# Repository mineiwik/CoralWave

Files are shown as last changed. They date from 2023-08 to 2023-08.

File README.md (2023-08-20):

# CoralWave

This repository contains the hardware design files for an RF transceiver system built using an ESP32-C3 module and a CC1101 RF chip. The communication between the ESP32-C3 and CC1101 is established through the Serial Peripheral Interface (SPI) protocol. The design is created using KiCad 7.

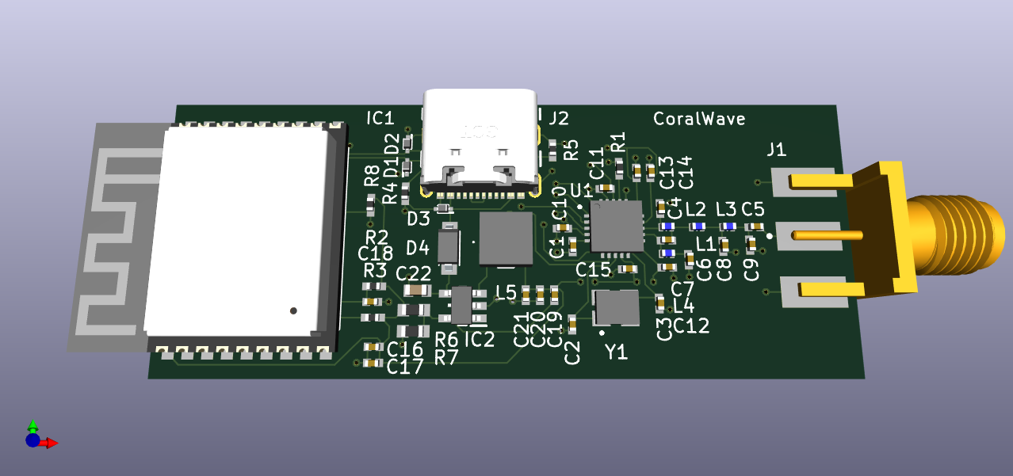
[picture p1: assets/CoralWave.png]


## Abstract

The project aims to create a versatile RF communication system by integrating the ESP32-C3 module and the CC1101 RF chip. The ESP32-C3 serves as the main controller, handling data processing and interfacing with external devices, while the CC1101 handles the RF communication with other compatible devices. This design allows for bi-directional communication over a designated RF frequency band, making it suitable for various applications such as replacing remote controls.

**Note:** The design around the CC1101 chip is tuned for the 315/433 MHz ISM/SRD frequency bands. (See the documentation of the [CC1101](https://www.ti.com/lit/ds/symlink/cc1101.pdf) chip for more information.)

## Opening the Design

Follow these steps to open the hardware design using KiCad 7:

1. Clone this repository to your local machine using the following command:

   ```
   git clone https://github.com/mineiwik/CoralWave.git
   ```

2. Launch KiCad 7.

3. Open the KiCad project by navigating to the project directory and locating the `.kicad_pro` file. This file stores the project information.

4. Once the project is open, you can access the schematic and PCB layout files by clicking on the respective buttons in the KiCad project manager.

5. Adjust the design and/or export the gerbel files for PCB production

## Design Files

The repository contains the following design files:

- Schematic files (`.kicad_sch`) - These files define the circuit connections and component values.
- PCB layout files (`.kicad_pcb`) - These files represent the physical arrangement of components on the PCB.
- Component libraries (see the `PCBLib` submodule) - Custom libraries that include footprints and symbols for the ESP32-C3, CC1101, and other components used in the design.

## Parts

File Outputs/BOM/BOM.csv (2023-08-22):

Id | Designator | Footprint | Quantity | Designation | Manufacturer Nr. | Mouser Nr.
1 | Y1 | NX3225GA16000MSTDCRG1 | 1 | NX3225GA-26MHZ | NX3225GA-26.000MHZ-EXS00A-CG01972 | 344-NX3225GA26MHZEXS
2 | C16,C1,C10 | Cap_Murata_GRM_0402 | 3 | 100nF | GRM155C71H104JE19J | 81-GRM155C71H104JE9J
3 | C2,C3 | Cap_Murata_GRM_0402 | 2 | 27pF | GRM1555C1H270JA01D | 81-GRM1555C1H270JA1D
4 | C5,C6,C13,C11,C12 | Cap_Murata_GRM_0402 | 5 | 220pF | GRM1555C1H221JA01J | 81-GRM1555C1H221JA1J
5 | U1 | CC1101RGP | 1 | CC1101RGP | CC1101RGPR | 595-CC1101RGPR
6 | R6 | R_Bourns_CR_0603 | 1 | 442k | CR0603-FX-4423ELF | 652-CR0603FX4423ELF
7 | C19 | Cap_Murata_GRM_0402 | 1 | 6.8pF | GRM1555C1E6R8BA01D | 81-GRM1555C1E6R8BA1D
8 | R8,R2,R3 | R_Vishay_CRCW_0402 | 3 | 10k | CRCW040210K0FKEDC | 71-CRCW040210K0FKEDC
9 | C22 | Cap_Murata_GRM_0603 | 1 | 4.7uF | GRM188R61C475KE11D | 81-GRM188R61C475KE1D
10 | R7 | R_Bourns_CR_0603 | 1 | 97.6k | CR0603-FX-9762ELF | 652-CR0603FX-9762ELF
11 | L3,L4,L1 | L_Murata_LQG_0402 | 3 | 27nH | LQG15HS27NJ02D | 81-LQG15HS27NJ02D
12 | C20,C17,C21 | Cap_Murata_GRM_0402 | 3 | 10uF | GRM155R61A106ME11D | 81-GRM155R61A106ME1D
13 | D4 | SOD3716X135N | 1 | B5819W-TP | B5819W-TP | 833-B5819W-TP
14 | D3,D2,D1 | SODFL1006X40N | 3 | CPDQ5V0-HF | CPDQ5V0-HF | 750-CPDQ5V0-HF
15 | R1 | R_KOA_RK_0402 | 1 | 56k | RK73H1ETTP5602F | 660-RK73H1ETTP5602F
16 | J1 | Molex-SD-73251-129 | 1 | 73251-1290 | 73251-1290 | 538-73251-1290
17 | R4,R5 | R_Vishay_CRCW_0402 | 2 | 5k1 | CRCW04025K10FKEDC | 71-CRCW04025K10FKEDC
18 | C7,C4 | Cap_Murata_GRM_0402 | 2 | 3.9pF | GRM1555C1H3R9CA01D | 81-GRM1555C1H3R9CA1D
19 | J2 | GCT_USB4105-GF-A | 1 | USB4105-GF-A | USB4105-GF-A | 640-USB4105-GF-A
20 | IC1 | ESP32C3WROOM02N4 | 1 | ESP32-C3-WROOM-02-N4 | ESP32-C3-WROOM-02-N4 | 356-ESP32C3WROOM02N4
21 | C8 | Cap_Murata_GRM_0402 | 1 | 8.2pF | GRM1555C1H8R2BA01D | 81-GRM1555C1H8R2BA1D
22 | C18 | Cap_Murata_GRM_0402 | 1 | 1uF | GRM155C81A105KA12J | 81-GRM155C81A105KA2J
23 | C9 | Cap_Murata_GRM_0402 | 1 | 5.6pF | GRM1555C1E5R6CA01D | 81-GRM1555C1E5R6CA1D
24 | C15,C14 | Cap_Murata_GRM_0402 | 2 | 10nF | GRM155R71E103KA01D | 81-GRM36X103K25
25 | L2 | L_Murata_LQG_0402 | 1 | 22nH | LQG15HS22NJ02D | 81-LQG15HS22NJ02D
26 | L5 | ASPI0418FS | 1 | 2.2uH | ASPI-0418FS-2R2M-T3 | 815-ASPI418FS2R2MT3
27 | IC2 | TLV62568DBVR | 1 | TLV62568DBVR | TLV62568DBVR | 595-TLV62568DBVR

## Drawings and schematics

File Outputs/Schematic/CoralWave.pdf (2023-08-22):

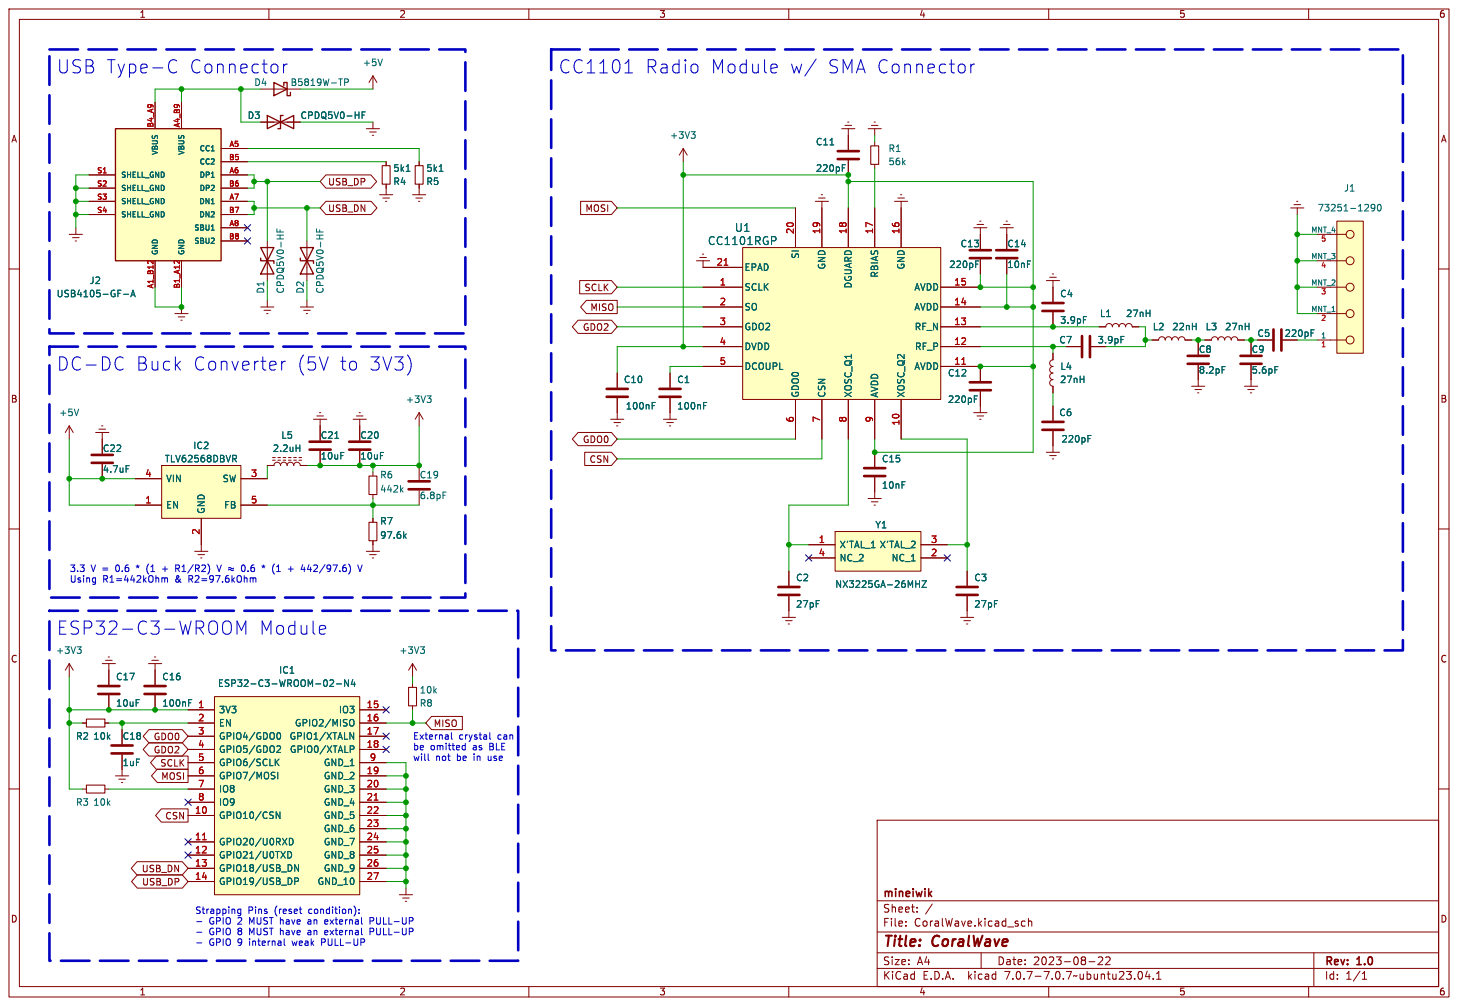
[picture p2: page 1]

DC-DC Buck Converter (5V to 3V3)

File: CoralWave.kicad_sch Sheet: / mineiwik

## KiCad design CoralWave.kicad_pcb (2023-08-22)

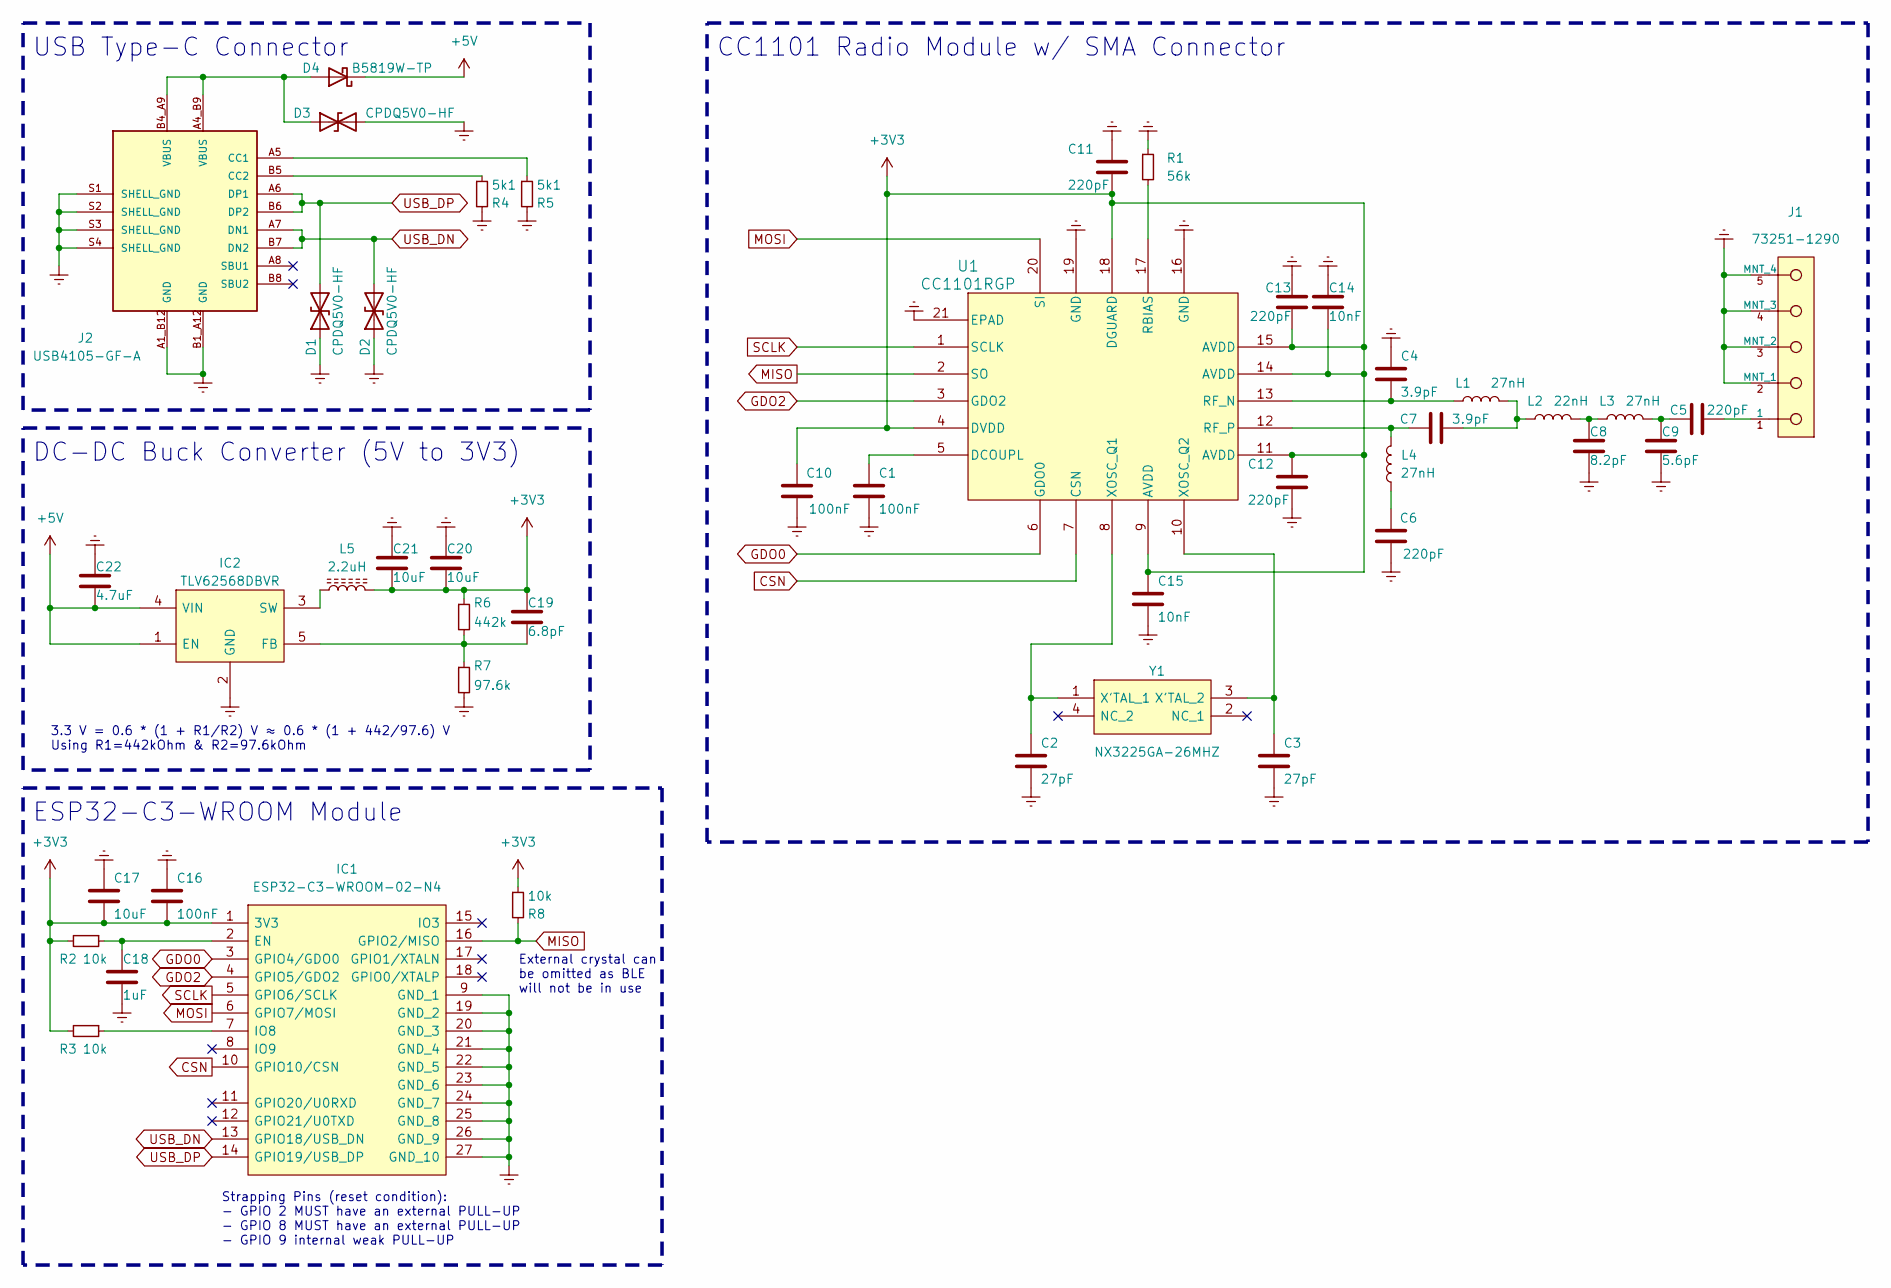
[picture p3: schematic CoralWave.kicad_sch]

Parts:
C1, C10, C16: 100nF; Cap_Murata_GRM_0402
C2, C3: 27pF; Cap_Murata_GRM_0402
C4, C7: 3.9pF; Cap_Murata_GRM_0402
C5, C6, C11, C12, C13: 220pF; Cap_Murata_GRM_0402
C8: 8.2pF; Cap_Murata_GRM_0402
C9: 5.6pF; Cap_Murata_GRM_0402
C14, C15: 10nF; Cap_Murata_GRM_0402
C17, C20, C21: 10uF; Cap_Murata_GRM_0402
C18: 1uF; Cap_Murata_GRM_0402
C19: 6.8pF; Cap_Murata_GRM_0402
C22: 4.7uF; Cap_Murata_GRM_0603
D1, D2, D3: CPDQ5V0-HF; SODFL1006X40N
D4: B5819W-TP; SOD3716X135N
IC1: ESP32-C3-WROOM-02-N4; ESP32C3WROOM02N4; Mouser Part Number 356-ESP32C3WROOM02N4
IC2: TLV62568DBVR; Mouser Part Number 595-TLV62568DBVR
J1: 73251-1290; Molex-SD-73251-129; mouser part number 538-73251-1290; digikey description SMA Connector Jack, Female Socket 50 Oh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
J2: USB4105-GF-A; GCT_USB4105-GF-A; PARTREV A3
L1, L3, L4: 27nH; L_Murata_LQG_0402
L2: 22nH; L_Murata_LQG_0402
L5: 2.2uH; ASPI0418FS
R1: 56k; R_KOA_RK_0402
R2, R3, R8: 10k; R_Vishay_CRCW_0402
R4, R5: 5k1; R_Vishay_CRCW_0402
R6: 442k; R_Bourns_CR_0603
R7: 97.6k; R_Bourns_CR_0603
U1: CC1101RGP
Y1: NX3225GA-26MHZ; NX3225GA16000MSTDCRG1; Mouser Part Number 344-NX3225GA26MHZEXS

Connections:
+3V3: C10.2, C11.2, C12.1, C13.2, C14.2, C15.1, C16.2, C17.2, C19.2, C20.2, C21.2, IC1.1 (3V3), L5.2, R2.2, R3.2, R6.1, R8.1, U1.4 (DVDD), U1.9 (AVDD), U1.11 (AVDD), U1.14 (AVDD), U1.15 (AVDD), U1.18 (DGUARD)
+5V: C22.1, D4.1 (K), IC2.1 (EN), IC2.4 (VIN)
CSN: IC1.10 (GPIO10/CSN), U1.7 (CSN)
Earth: C1.2, C2.2, C3.2, C4.1, C6.1, C8.1, C9.1, C10.1, C11.1, C12.2, C13.1, C14.1, C15.2, C16.1, C17.1, C18.2, C20.1, C21.1, C22.2, D1.1 (A1), D2.1 (A1), D3.2 (A2), IC1.9 (GND_1), IC1.19 (GND_2), IC1.20 (GND_3), IC1.21 (GND_4), IC1.22 (GND_5), IC1.23 (GND_6), IC1.24 (GND_7), IC1.25 (GND_8), IC1.26 (GND_9), IC1.27 (GND_10), IC2.2 (GND), J1.2 (MNT_1), J1.3 (MNT_2), J1.4 (MNT_3), J1.5 (MNT_4), J2.A1_B12 (GND), J2.B1_A12 (GND), J2.S1 (SHELL_GND), J2.S2 (SHELL_GND), J2.S3 (SHELL_GND), J2.S4 (SHELL_GND), R1.1, R4.2, R5.2, R7.2, U1.16 (GND), U1.19 (GND), U1.21 (EPAD)
GDO0: IC1.3 (GPIO4/GDO0), U1.6 (GDO0)
GDO2: IC1.4 (GPIO5/GDO2), U1.3 (GDO2)
MISO: IC1.16 (GPIO2/MISO), R8.2, U1.2 (SO)
MOSI: IC1.6 (GPIO7/MOSI), U1.20 (SI)
unnamed: C5.1, C9.2, L3.2
unnamed: C5.2, J1.1
unnamed: C6.2, L4.1
unnamed: C7.2, L1.2, L2.1
unnamed: C8.2, L2.2, L3.1
unnamed: D3.1 (A1), D4.2 (A), J2.A4_B9 (VBUS), J2.B4_A9 (VBUS)
unnamed: C18.1, IC1.2 (EN), R2.1
unnamed: IC1.7 (IO8), R3.1
unnamed: C19.1, IC2.5 (FB), R6.2, R7.1
unnamed: IC2.3 (SW), L5.1
unnamed: J2.A5 (CC1), R5.1
unnamed: J2.B5 (CC2), R4.1
unnamed: C1.1, U1.5 (DCOUPL)
unnamed: R1.2, U1.17 (RBIAS)
unnamed: C4.2, L1.1, U1.13 (RF_N)
unnamed: C7.1, L4.2, U1.12 (RF_P)
unnamed: C2.1, U1.8 (XOSC_Q1), Y1.1 (X'TAL_1)
unnamed: C3.1, U1.10 (XOSC_Q2), Y1.3 (X'TAL_2)
SCLK: IC1.5 (GPIO6/SCLK), U1.1 (SCLK)
USB_DN: D2.2 (A2), IC1.13 (GPIO18/USB_DN), J2.A7 (DN1), J2.B7 (DN2)
USB_DP: D1.2 (A2), IC1.14 (GPIO19/USB_DP), J2.A6 (DP1), J2.B6 (DP2)

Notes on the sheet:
Strapping Pins (reset condition): - GPIO 2 MUST have an external PULL-UP - GPIO 8 MUST have an external PULL-UP - GPIO 9 internal weak PULL-UP
CC1101 Radio Module w/ SMA Connector
3.3 V = 0.6 * (1 + R1/R2) V ≈ 0.6 * (1 + 442/97.6) V Using R1=442kOhm & R2=97.6kOhm
DC-DC Buck Converter (5V to 3V3)
ESP32-C3-WROOM Module
External crystal can be omitted as BLE will not be in use
USB Type-C Connector

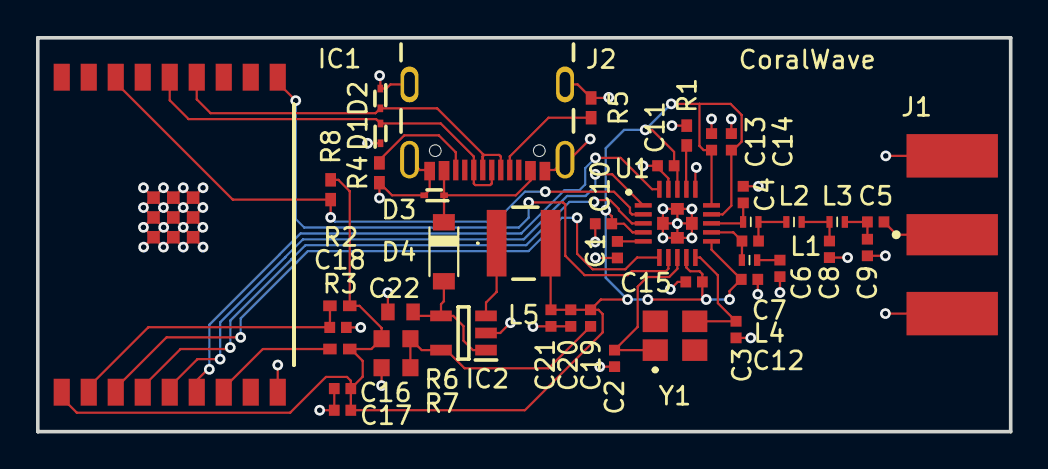
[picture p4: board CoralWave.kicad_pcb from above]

Board: 2 copper layers, 54.0 x 21.9 mm, 45 parts (0 on the bottom side), 29 nets.

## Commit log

2023-08-22 Add BOM
    [BOM.csv, CoralWave.kicad_sch]
2023-08-22 Regenerate fab files
    [CoralWave-B_Cu.gbl, CoralWave-B_Mask.gbs, CoralWave-B_Paste.gbp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]
